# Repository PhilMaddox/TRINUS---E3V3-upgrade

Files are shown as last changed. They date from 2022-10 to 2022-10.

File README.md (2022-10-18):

# TRINUS---BTT_E3V3-control board
Firmware files to operate a BTT E3V3 control board on a Trinus printer
Based on the Marlin 2.1.1 released version. 

## Trinus basic model - No heated bed 
This firmware contains the operational PID controller for the bed just set the bed temp to zero in your slicer

## Heated Bed 
There are 2 types of trinus heated bed

Type 1 - Has onboard control for bed temp 60 or 90 deg via a switch This board needs 12VDC power

Type 2 - Upgraded bed allowing for temp control from software / gcode 
         Direct replacement for Type 1 style board and came with cable for connection to the Panowin control board.

Trinus Panowin bed Type 2

Type 3 - Upgraded longer bed with manual leveling system.  Kodama Heated Bed is controlled from the Bardo control board but has
         non standard wiring as the temp control MOSFET is on the bed boad itself.
         Was supplied as kit with bed , springs, screws , thumb nuts, glass bed & clips 
         
         Note : A solution to allow the bed to be controlled from the E3V3 main control is to be found in the Heated Bed Mod folder
         The modification will suit most commonly available control boards

## STL Folder
Contains STL files for an adapter plate to fit the E3V3 board to a Trinus printer and a bracket for a
control board "case" cooling fan. Either 30X30X10 or 40X40X10

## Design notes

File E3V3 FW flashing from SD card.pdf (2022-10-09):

1. Format an SD card ( 16 GB or less SD card recommended)
2. Copy the firmware.bin file onto the SD card ( must be called firmware.bin)

In Win10 eject the SD card ( right click, select eject from the pull down menu) This to prevent files getting corrupted when SD card is removed from PC

3.

4. Power on the control board
5. Insert the SD card
6. Press reset on the control board ( press and hold for 1 sec)

After 10 secs you should see the red activity LED go off then come on and start flashing

7.

8. Remove the SD card
9. Press reset on the control board

Read the card on the PC The name should be FIRMWARE.CUR if the firmware has flashed correctly

10.

Connect to the computer and in Pronterface send the M502 then M500 command

11.

Or with attached LCD select "Load Settings" then "Save Settings"

12. By sending M503 you can read the current settings

## E3V3 FW flashing from SD card

Thursday, 6 October 2022 10:06 AM

PMSG 3D printer info Page 1

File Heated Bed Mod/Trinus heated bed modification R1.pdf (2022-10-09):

### Foreword

Due to the way the Kodama Trinus bed & the Bardo V1.3 board work, the bed cannot be simply wired to a typical Marlin control board.

The Kodama heated bed has an onboard Mosfet that regulates the temperature and the onboard Mosfet is driven via a simple single wire connection that applies PWM +4.8 VDC to turn the heater on and +/- 0.2 VDC to turn it off.

The 4 core cable from the Bardo board is made up of
Black = +12 VDC
Green Yellow = GND
Brown = Heating control
Blue = Thermistor

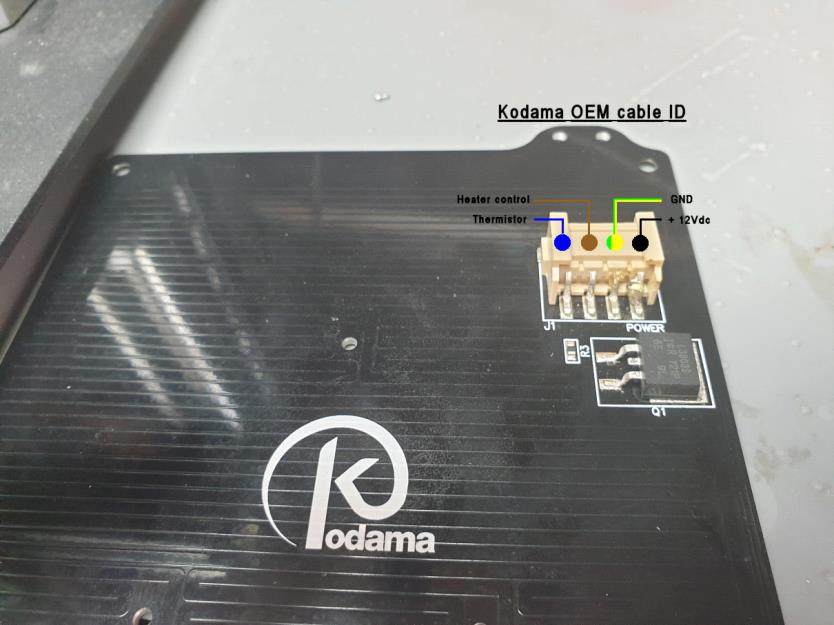
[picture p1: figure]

So in essence this is a heated bed that is always powered and is controlled by single 5 volt line (brown) while giving temp feedback on a single line (blue)

After considering many options for adaptation, I decided on the easiest and most straight forward to realise. Also allowing for a return to the original if this were ever needed. So a non-destructive adaptation.

### MODIFICATION

As the OEM bed wiring is very stiff I opted for silicone cable that I typically use on all 3D printers rather than adapt the OEM wiring.

The respective Red and Black wires were soldered to the +12Vdc & GND for testing purposes Once terminals for the bed plug are available the solder connection will be replaced

I installed a "glass bead" style thermistor with the use of Kapton tape.

# Trinus heated bed modification

Sunday, 9 October 2022 8:27 PM

TRINUS mods Page 1

### Cont'd

After researching the onboard Kodama Mosfet ( L3803S) I solder linked the Drain & Source together. In effect by passing the HB Mosfet

The HB "on board" white power LED still mm works in as much as it follows the duty cycle of the PWM signal being supplied to the heated bed.

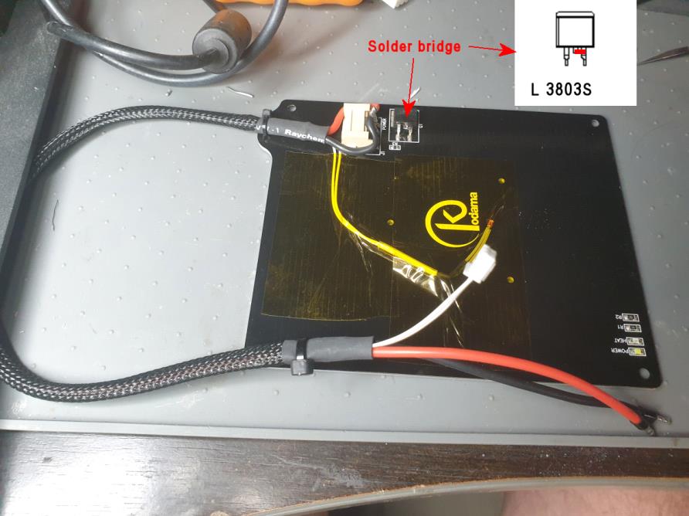
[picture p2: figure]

TRINUS mods Page 2

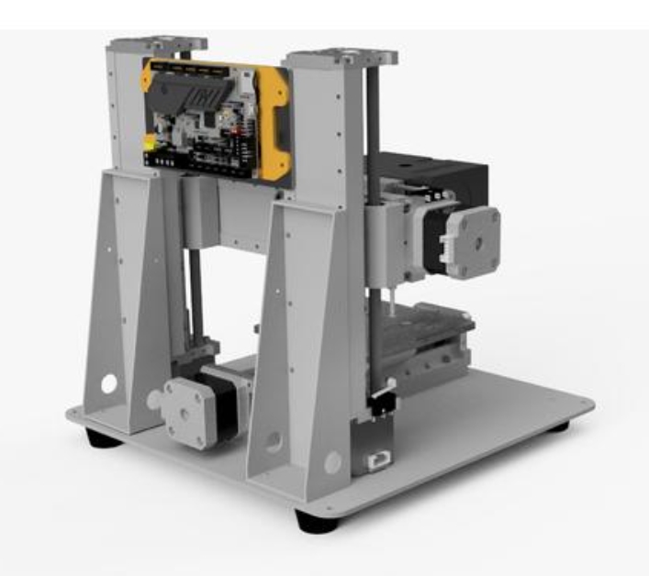
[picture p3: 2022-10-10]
STL/E3V3 adapter Trinus.jpg

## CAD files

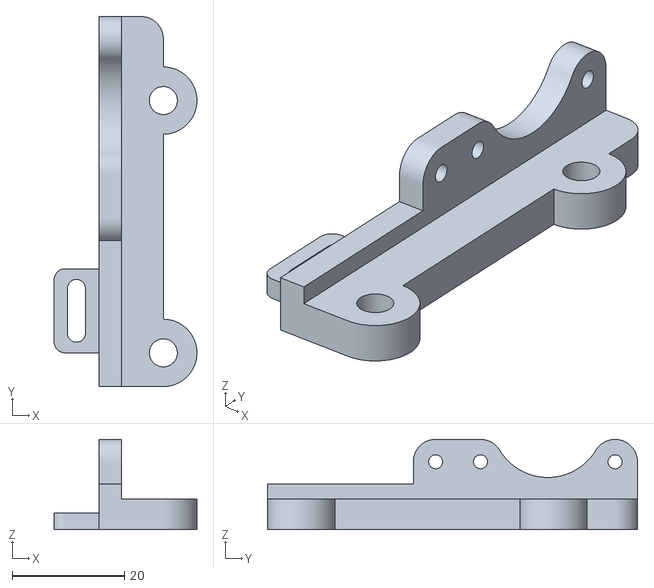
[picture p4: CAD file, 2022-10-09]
STL/PM_Trinus_E3V3_Fan_bracket.stl
25.5 x 66.0 x 16.1

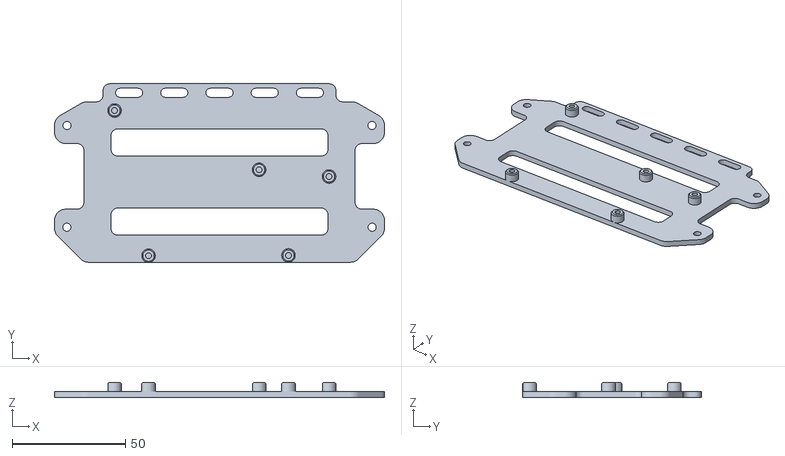
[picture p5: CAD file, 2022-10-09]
STL/PM_Trinus_Adapter_plate_E3V3_R3_.stl
146.0 x 79.0 x 6.60

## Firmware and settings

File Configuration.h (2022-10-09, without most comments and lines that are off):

#pragma once
#define CONFIG_EXAMPLES_DIR "Creality/Ender-3 Pro/BigTreeTech SKR Mini E3 3.0"
#define CONFIGURATION_H_VERSION 02010100
#define STRING_CONFIG_H_AUTHOR "(Philm,TRINUS R1)" // Who made the changes.
  #define MOTHERBOARD BOARD_BTT_SKR_MINI_E3_V3_0
#define SERIAL_PORT 2
#define BAUDRATE 115200
#define SERIAL_PORT_2 -1
#define CUSTOM_MACHINE_NAME "TRINUS"
#define X_DRIVER_TYPE  TMC2209
#define Y_DRIVER_TYPE  TMC2209
#define Z_DRIVER_TYPE  TMC2209
#define E0_DRIVER_TYPE TMC2209
#define EXTRUDERS 1
#define DEFAULT_NOMINAL_FILAMENT_DIA 1.75
#define TEMP_SENSOR_0 1
#define TEMP_SENSOR_1 0
#define TEMP_SENSOR_2 0
#define TEMP_SENSOR_3 0
#define TEMP_SENSOR_4 0
#define TEMP_SENSOR_5 0
#define TEMP_SENSOR_6 0
#define TEMP_SENSOR_7 0
#define TEMP_SENSOR_BED 1
#define TEMP_SENSOR_PROBE 0
#define TEMP_SENSOR_CHAMBER 0
#define TEMP_SENSOR_COOLER 0
#define TEMP_SENSOR_BOARD 0
#define TEMP_SENSOR_REDUNDANT 0
#define DUMMY_THERMISTOR_998_VALUE  25
#define DUMMY_THERMISTOR_999_VALUE 100
#if TEMP_SENSOR_IS_MAX_TC(0)
  #define MAX31865_SENSOR_OHMS_0      100 // (Ω) Typically 100 or 1000 (PT100 or PT1000)
  #define MAX31865_CALIBRATION_OHMS_0 430 // (Ω) Typically 430 for Adafruit PT100; 4300 for Adafruit PT1000
#endif
#if TEMP_SENSOR_IS_MAX_TC(1)
  #define MAX31865_SENSOR_OHMS_1      100
  #define MAX31865_CALIBRATION_OHMS_1 430
#endif
#if HAS_E_TEMP_SENSOR
  #define TEMP_RESIDENCY_TIME         10  // (seconds) Time to wait for hotend to "settle" in M109
  #define TEMP_WINDOW                  1  // (°C) Temperature proximity for the "temperature reached" timer
  #define TEMP_HYSTERESIS              3  // (°C) Temperature proximity considered "close enough" to the target
#endif
#if TEMP_SENSOR_BED
  #define TEMP_BED_RESIDENCY_TIME     10  // (seconds) Time to wait for bed to "settle" in M190
  #define TEMP_BED_WINDOW              1  // (°C) Temperature proximity for the "temperature reached" timer
  #define TEMP_BED_HYSTERESIS          3  // (°C) Temperature proximity considered "close enough" to the target
#endif
#if TEMP_SENSOR_CHAMBER
  #define TEMP_CHAMBER_RESIDENCY_TIME 10  // (seconds) Time to wait for chamber to "settle" in M191
  #define TEMP_CHAMBER_WINDOW          1  // (°C) Temperature proximity for the "temperature reached" timer
  #define TEMP_CHAMBER_HYSTERESIS      3  // (°C) Temperature proximity considered "close enough" to the target
#endif
#if TEMP_SENSOR_REDUNDANT
  #define TEMP_SENSOR_REDUNDANT_SOURCE    E1  // The sensor that will provide the redundant reading.
  #define TEMP_SENSOR_REDUNDANT_TARGET    E0  // The sensor that we are providing a redundant reading for.
  #define TEMP_SENSOR_REDUNDANT_MAX_DIFF  10  // (°C) Temperature difference that will trigger a print abort.
#endif
#define HEATER_0_MINTEMP   5
#define HEATER_1_MINTEMP   5
#define HEATER_2_MINTEMP   5
#define HEATER_3_MINTEMP   5
#define HEATER_4_MINTEMP   5
#define HEATER_5_MINTEMP   5
#define HEATER_6_MINTEMP   5
#define HEATER_7_MINTEMP   5
#define BED_MINTEMP        5
#define CHAMBER_MINTEMP    5
#define HEATER_0_MAXTEMP 275
#define HEATER_1_MAXTEMP 275
#define HEATER_2_MAXTEMP 275
#define HEATER_3_MAXTEMP 275
#define HEATER_4_MAXTEMP 275
#define HEATER_5_MAXTEMP 275
#define HEATER_6_MAXTEMP 275
#define HEATER_7_MAXTEMP 275
#define BED_MAXTEMP      150
#define CHAMBER_MAXTEMP  60
#define HOTEND_OVERSHOOT 15   // (°C) Forbid temperatures over MAXTEMP - OVERSHOOT
#define BED_OVERSHOOT    10   // (°C) Forbid temperatures over MAXTEMP - OVERSHOOT
#define COOLER_OVERSHOOT  2   // (°C) Forbid temperatures closer than OVERSHOOT
#define PIDTEMP          // See the PID Tuning Guide at https://reprap.org/wiki/PID_Tuning
#define BANG_MAX 255     // Limits current to nozzle while in bang-bang mode; 255=full current
#define PID_MAX BANG_MAX // Limits current to nozzle while PID is active (see PID_FUNCTIONAL_RANGE below); 255=full current
#define PID_K1 0.95      // Smoothing factor within any PID loop
    #define DEFAULT_Kp  22.08
    #define DEFAULT_Ki   1.09
    #define DEFAULT_Kd  115.57
#define PIDTEMPBED
#define MAX_BED_POWER 255 // limits duty cycle to bed; 255=full current
  #define DEFAULT_bedKp 10.00
  #define DEFAULT_bedKi 0.023
  #define DEFAULT_bedKd 305.4
#define MAX_CHAMBER_POWER 255 // limits duty cycle to chamber heater; 255=full current
  #define PID_FUNCTIONAL_RANGE 10 // If the temperature difference between the target temperature and the actual temperature
#define PREVENT_COLD_EXTRUSION
#define EXTRUDE_MINTEMP 170
#define PREVENT_LENGTHY_EXTRUDE
#define EXTRUDE_MAXLENGTH 600
#define THERMAL_PROTECTION_HOTENDS // Enable thermal protection for all extruders
#define THERMAL_PROTECTION_BED     // Enable thermal protection for the heated bed
#define THERMAL_PROTECTION_CHAMBER // Enable thermal protection for the heated chamber
#define THERMAL_PROTECTION_COOLER  // Enable thermal protection for the laser cooling
#define USE_XMIN_PLUG
#define USE_YMIN_PLUG
#define USE_ZMIN_PLUG
#define ENDSTOPPULLUPS
#define X_MIN_ENDSTOP_INVERTING true // Set to true to invert the logic of the endstop.
#define Y_MIN_ENDSTOP_INVERTING true // Set to true to invert the logic of the endstop.
#define Z_MIN_ENDSTOP_INVERTING true // Set to true to invert the logic of the endstop.
#define I_MIN_ENDSTOP_INVERTING false // Set to true to invert the logic of the endstop.
#define J_MIN_ENDSTOP_INVERTING false // Set to true to invert the logic of the endstop.
#define K_MIN_ENDSTOP_INVERTING false // Set to true to invert the logic of the endstop.
#define U_MIN_ENDSTOP_INVERTING false // Set to true to invert the logic of the endstop.
#define V_MIN_ENDSTOP_INVERTING false // Set to true to invert the logic of the endstop.
#define W_MIN_ENDSTOP_INVERTING false // Set to true to invert the logic of the endstop.
#define X_MAX_ENDSTOP_INVERTING false // Set to true to invert the logic of the endstop.
#define Y_MAX_ENDSTOP_INVERTING false // Set to true to invert the logic of the endstop.
#define Z_MAX_ENDSTOP_INVERTING false // Set to true to invert the logic of the endstop.
#define I_MAX_ENDSTOP_INVERTING false // Set to true to invert the logic of the endstop.
#define J_MAX_ENDSTOP_INVERTING false // Set to true to invert the logic of the endstop.
#define K_MAX_ENDSTOP_INVERTING false // Set to true to invert the logic of the endstop.
#define U_MAX_ENDSTOP_INVERTING false // Set to true to invert the logic of the endstop.
#define V_MAX_ENDSTOP_INVERTING false // Set to true to invert the logic of the endstop.
#define W_MAX_ENDSTOP_INVERTING false // Set to true to invert the logic of the endstop.
#define Z_MIN_PROBE_ENDSTOP_INVERTING true // Set to true to invert the logic of the probe.
#define DEFAULT_AXIS_STEPS_PER_UNIT   { 228, 228, 228, 96 }
#define DEFAULT_MAX_FEEDRATE          { 500, 500, 5, 25 }
#define DEFAULT_MAX_ACCELERATION      { 500, 500, 100, 5000 }
#define DEFAULT_ACCELERATION           500  // X, Y, Z ... and E acceleration for printing moves
#define DEFAULT_RETRACT_ACCELERATION   500  // E acceleration for retracts
#define DEFAULT_TRAVEL_ACCELERATION    500  // X, Y, Z ... acceleration for travel (non printing) moves
#define DEFAULT_EJERK    5.0  // May be used by Linear Advance
  #define JUNCTION_DEVIATION_MM 0.08 // (mm) Distance from real junction edge
  #define JD_HANDLE_SMALL_SEGMENTS    // Use curvature estimation instead of just the junction angle
#define S_CURVE_ACCELERATION
#define NOZZLE_TO_PROBE_OFFSET { -44, -8, 0 }
#define PROBING_MARGIN 10
#define XY_PROBE_FEEDRATE (50*60)// PM edit for trinus  ( was 133*60)
#define Z_PROBE_FEEDRATE_FAST (4*60)
#define Z_PROBE_FEEDRATE_SLOW (Z_PROBE_FEEDRATE_FAST / 2)
#define Z_CLEARANCE_DEPLOY_PROBE   10 // Z Clearance for Deploy/Stow
#define Z_CLEARANCE_BETWEEN_PROBES  5 // Z Clearance between probe points
#define Z_CLEARANCE_MULTI_PROBE     5 // Z Clearance between multiple probes
#define Z_PROBE_LOW_POINT          -2 // Farthest distance below the trigger-point to go before stopping
#define Z_PROBE_OFFSET_RANGE_MIN -20
#define Z_PROBE_OFFSET_RANGE_MAX 20
#define X_ENABLE_ON 0
#define Y_ENABLE_ON 0
#define Z_ENABLE_ON 0
#define E_ENABLE_ON 0 // For all extruders
#define DISABLE_X false
#define DISABLE_Y false
#define DISABLE_Z false
#define DISABLE_E false             // Disable the extruder when not stepping
#define DISABLE_INACTIVE_EXTRUDER   // Keep only the active extruder enabled
#define INVERT_X_DIR true
#define INVERT_Y_DIR true
#define INVERT_Z_DIR true //PM edit
#define INVERT_E0_DIR false   //PM edit
#define INVERT_E1_DIR false
#define INVERT_E2_DIR false
#define INVERT_E3_DIR false
#define INVERT_E4_DIR false
#define INVERT_E5_DIR false
#define INVERT_E6_DIR false
#define INVERT_E7_DIR false
#define X_HOME_DIR -1
#define Y_HOME_DIR -1
#define Z_HOME_DIR -1
#define X_BED_SIZE 120
#define Y_BED_SIZE 120
#define X_MIN_POS 0
#define Y_MIN_POS 0
#define Z_MIN_POS 0
#define X_MAX_POS X_BED_SIZE
#define Y_MAX_POS Y_BED_SIZE
#define Z_MAX_POS 125
#define MIN_SOFTWARE_ENDSTOPS
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

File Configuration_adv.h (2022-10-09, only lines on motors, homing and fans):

  #define CONTROLLER_FAN_PIN FAN2_PIN       // Set a custom pin for the controller fan
#define E0_AUTO_FAN_PIN FAN1_PIN
#define E1_AUTO_FAN_PIN -1
#define E2_AUTO_FAN_PIN -1
#define E3_AUTO_FAN_PIN -1
#define E4_AUTO_FAN_PIN -1
#define E5_AUTO_FAN_PIN -1
#define E6_AUTO_FAN_PIN -1
#define E7_AUTO_FAN_PIN -1
#define CHAMBER_AUTO_FAN_PIN -1
#define COOLER_AUTO_FAN_PIN -1
#define HOMING_BUMP_MM      { 4, 4, 2 }       // (linear=mm, rotational=°) Backoff from endstops after first bump
#define HOMING_BUMP_DIVISOR { 2, 2, 4 }       // Re-Bump Speed Divisor (Divides the Homing Feedrate)
#define MICROSTEP_MODES { 16, 16, 16, 16, 16, 16 } // [1,2,4,8,16]
  #define BABYSTEP_WITHOUT_HOMING
#define LIN_ADVANCE
  #define LIN_ADVANCE_K 0.0    // Unit: mm compression per 1mm/s extruder speed
#define ADVANCED_PAUSE_FEATURE
  #define ADVANCED_PAUSE_PURGE_FEEDRATE        3  // (mm/s) Extrude feedrate (after loading). Should be slower than load feedrate.
  #define ADVANCED_PAUSE_PURGE_LENGTH         50  // (mm) Length to extrude after loading.
  #define ADVANCED_PAUSE_RESUME_PRIME          0  // (mm) Extra distance to prime nozzle after returning from park.
  #define HOME_BEFORE_FILAMENT_CHANGE           // If needed, home before parking for filament change
    #define X_CURRENT       650       // (mA) RMS current. Multiply by 1.414 for peak current.
    #define X_CURRENT_HOME  X_CURRENT / 2  // (mA) RMS current for sensorless homing
    #define X_MICROSTEPS     16        // 0..256
    #define Y_CURRENT       650
    #define Y_CURRENT_HOME  Y_CURRENT / 2
    #define Y_MICROSTEPS     16
    #define Z_CURRENT       800
    #define Z_CURRENT_HOME  Z_CURRENT / 2
    #define Z_MICROSTEPS     16
    #define E0_CURRENT      750
    #define E0_MICROSTEPS    16
  #define X_HYBRID_THRESHOLD     100  // [mm/s]
  #define X2_HYBRID_THRESHOLD    100
  #define Y_HYBRID_THRESHOLD     100
  #define Y2_HYBRID_THRESHOLD    100
  #define Z_HYBRID_THRESHOLD       20
  #define Z2_HYBRID_THRESHOLD      3
  #define Z3_HYBRID_THRESHOLD      3
  #define Z4_HYBRID_THRESHOLD      3
  #define I_HYBRID_THRESHOLD       3  // [linear=mm/s, rotational=°/s]
  #define J_HYBRID_THRESHOLD       3  // [linear=mm/s, rotational=°/s]
  #define K_HYBRID_THRESHOLD       3  // [linear=mm/s, rotational=°/s]
  #define U_HYBRID_THRESHOLD       3  // [mm/s]
  #define V_HYBRID_THRESHOLD       3
  #define W_HYBRID_THRESHOLD       3
  #define E0_HYBRID_THRESHOLD     30
  #define E1_HYBRID_THRESHOLD     30
  #define E2_HYBRID_THRESHOLD     30
  #define E3_HYBRID_THRESHOLD     30
  #define E4_HYBRID_THRESHOLD     30
  #define E5_HYBRID_THRESHOLD     30
  #define E6_HYBRID_THRESHOLD     30
  #define E7_HYBRID_THRESHOLD     30

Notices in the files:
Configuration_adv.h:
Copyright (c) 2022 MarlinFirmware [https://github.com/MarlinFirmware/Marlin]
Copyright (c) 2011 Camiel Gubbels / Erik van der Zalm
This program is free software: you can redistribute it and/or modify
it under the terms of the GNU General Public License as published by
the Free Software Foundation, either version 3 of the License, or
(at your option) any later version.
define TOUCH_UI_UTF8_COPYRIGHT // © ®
